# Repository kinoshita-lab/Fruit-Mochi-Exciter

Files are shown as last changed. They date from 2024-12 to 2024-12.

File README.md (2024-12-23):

# Fruit Mochi Exciter

[日本語](README.ja.md)

Mochi(Fruit Mochi) is a famous Japanese sweets, which (from my perspective) looks like trigger pads what DJs/Musicians doing some kind of cool activities!
This product enables mochi lighting to derive full potential of the mochi itself...!


<br />
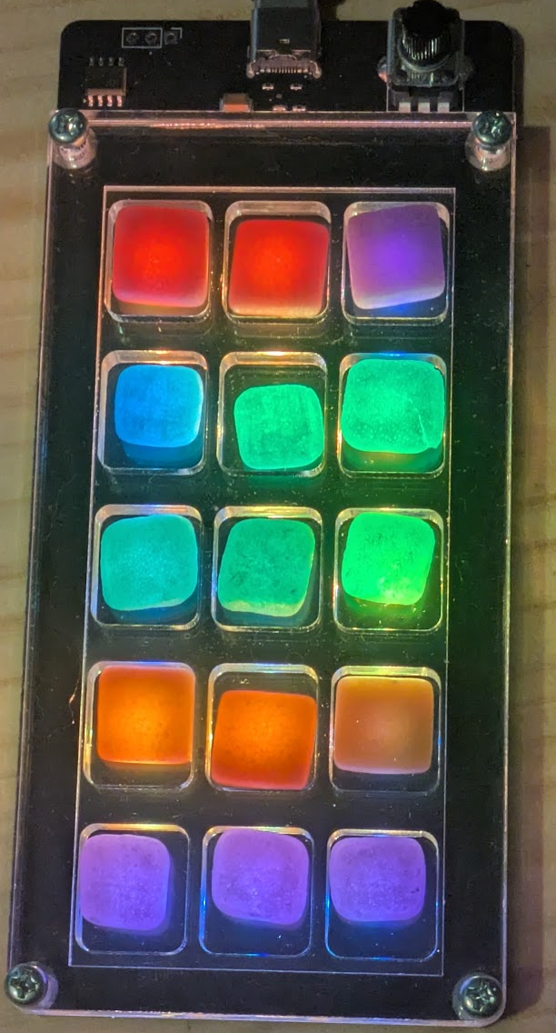
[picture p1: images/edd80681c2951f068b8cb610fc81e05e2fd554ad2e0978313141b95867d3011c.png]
  
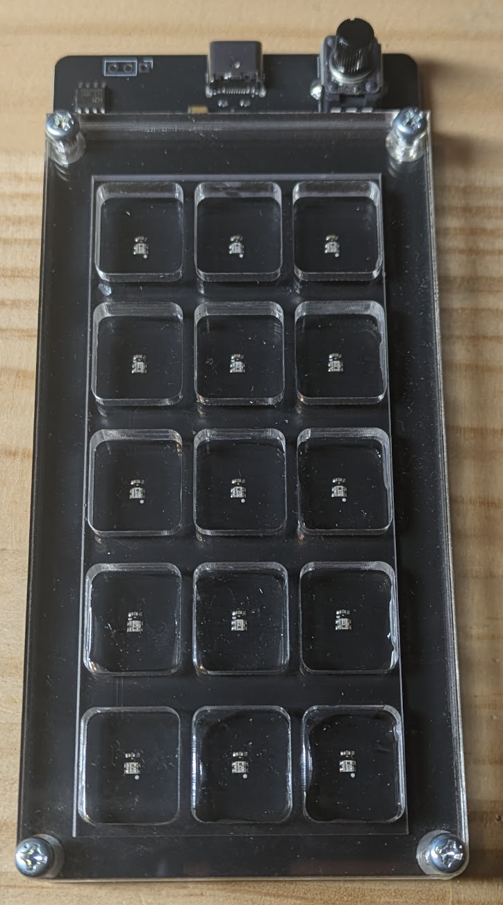
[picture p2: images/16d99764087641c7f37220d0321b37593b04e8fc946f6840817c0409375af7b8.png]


## Features

- Can change tempo via potentiometer

## Kit Contents

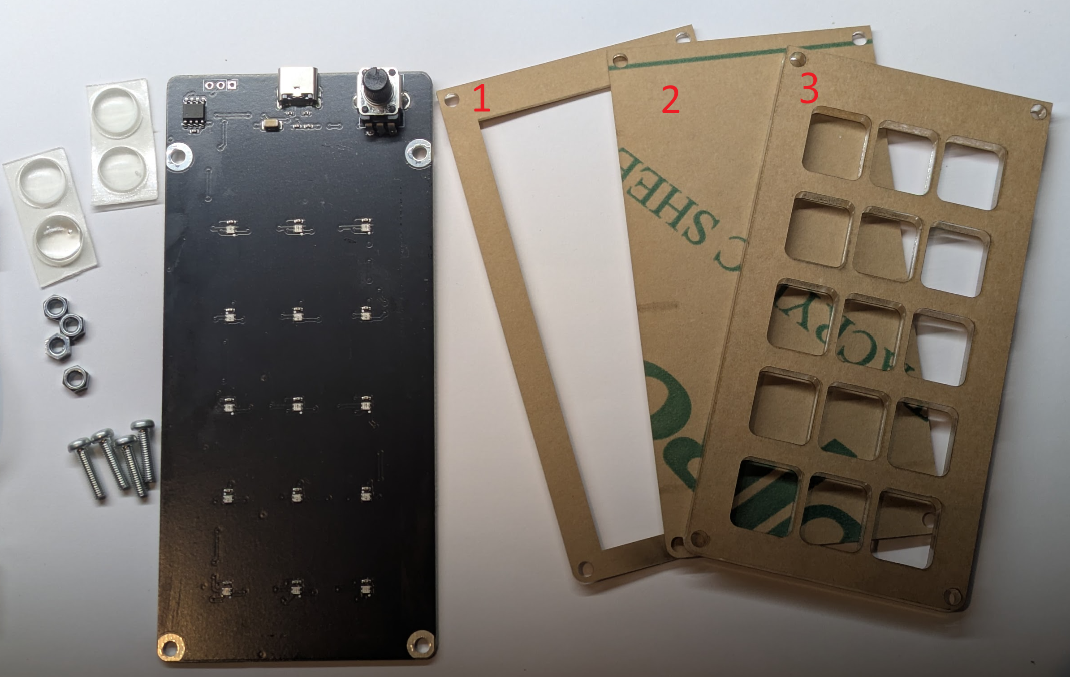
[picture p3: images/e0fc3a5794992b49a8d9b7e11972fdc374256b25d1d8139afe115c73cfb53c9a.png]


- Pre-assembled circuit board
- M3 12mm screws: 4pcs.
- M3 nuts: 4pcs.
- Acrylic boards(1, 2, 3)
- Rubber feets: 4pcs.

## What you will need

- USB Type-C cable, with connected to the power source(AC adapter, PC, etc.)
- Screwdriver
- Fruit Mochi: 15 pcs.

## How to assemble

- Remove the sealing paper on the accrylic boards.
- Put board 1 on the circuit board.
- Put board 2 on the board 1
- Put board 3 on the board 2
- Fix all with 12mm screws and nuts.

## How to use

- Place mochis on the board.
- Start lighting by connecting the USB.
- Enjoy!

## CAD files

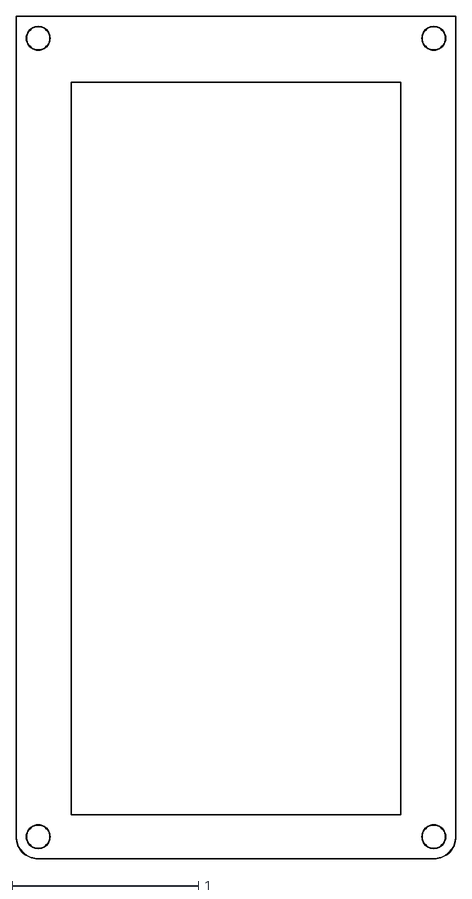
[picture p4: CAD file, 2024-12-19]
hard/Accryl/Fruit-Mochi-exciter_Acryl_Layer0-Edge_Cuts.dxf
2.36 x 4.53

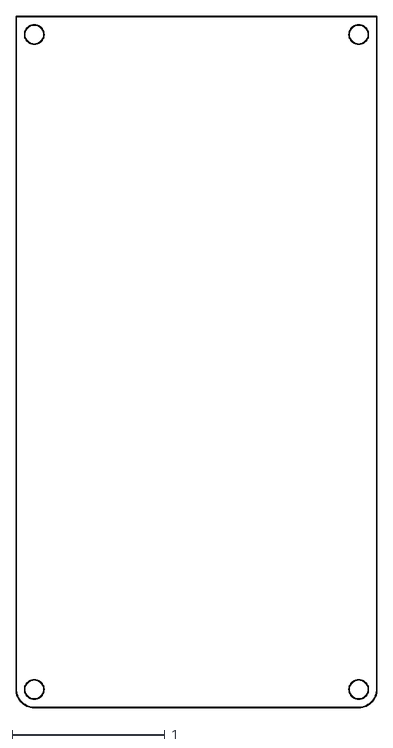
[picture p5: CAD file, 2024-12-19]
hard/Accryl/Fruit-Mochi-exciter_Acryl_Layer1-Edge_Cuts.dxf
2.36 x 4.53

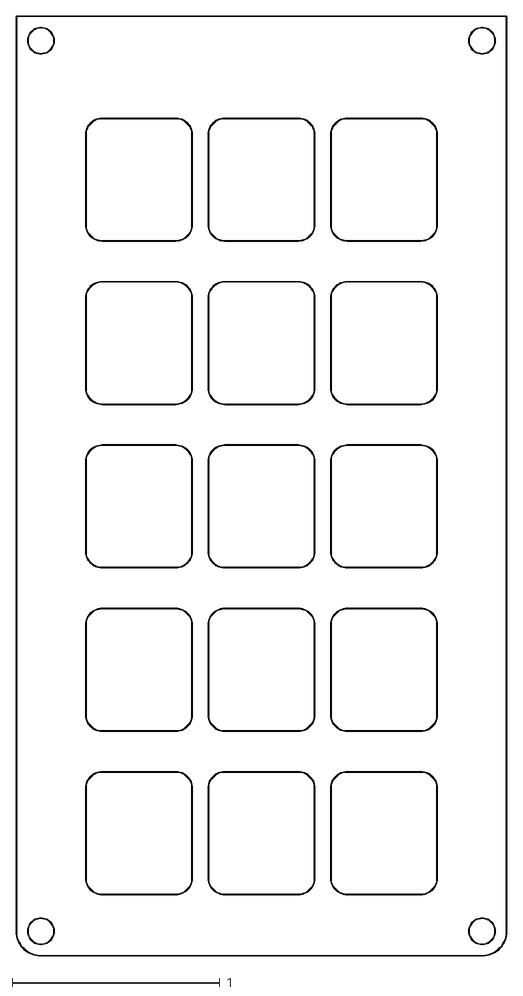
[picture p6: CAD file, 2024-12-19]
hard/Accryl/Fruit-Mochi-exciter_Acryl_Layer2-Edge_Cuts.dxf
2.36 x 4.53

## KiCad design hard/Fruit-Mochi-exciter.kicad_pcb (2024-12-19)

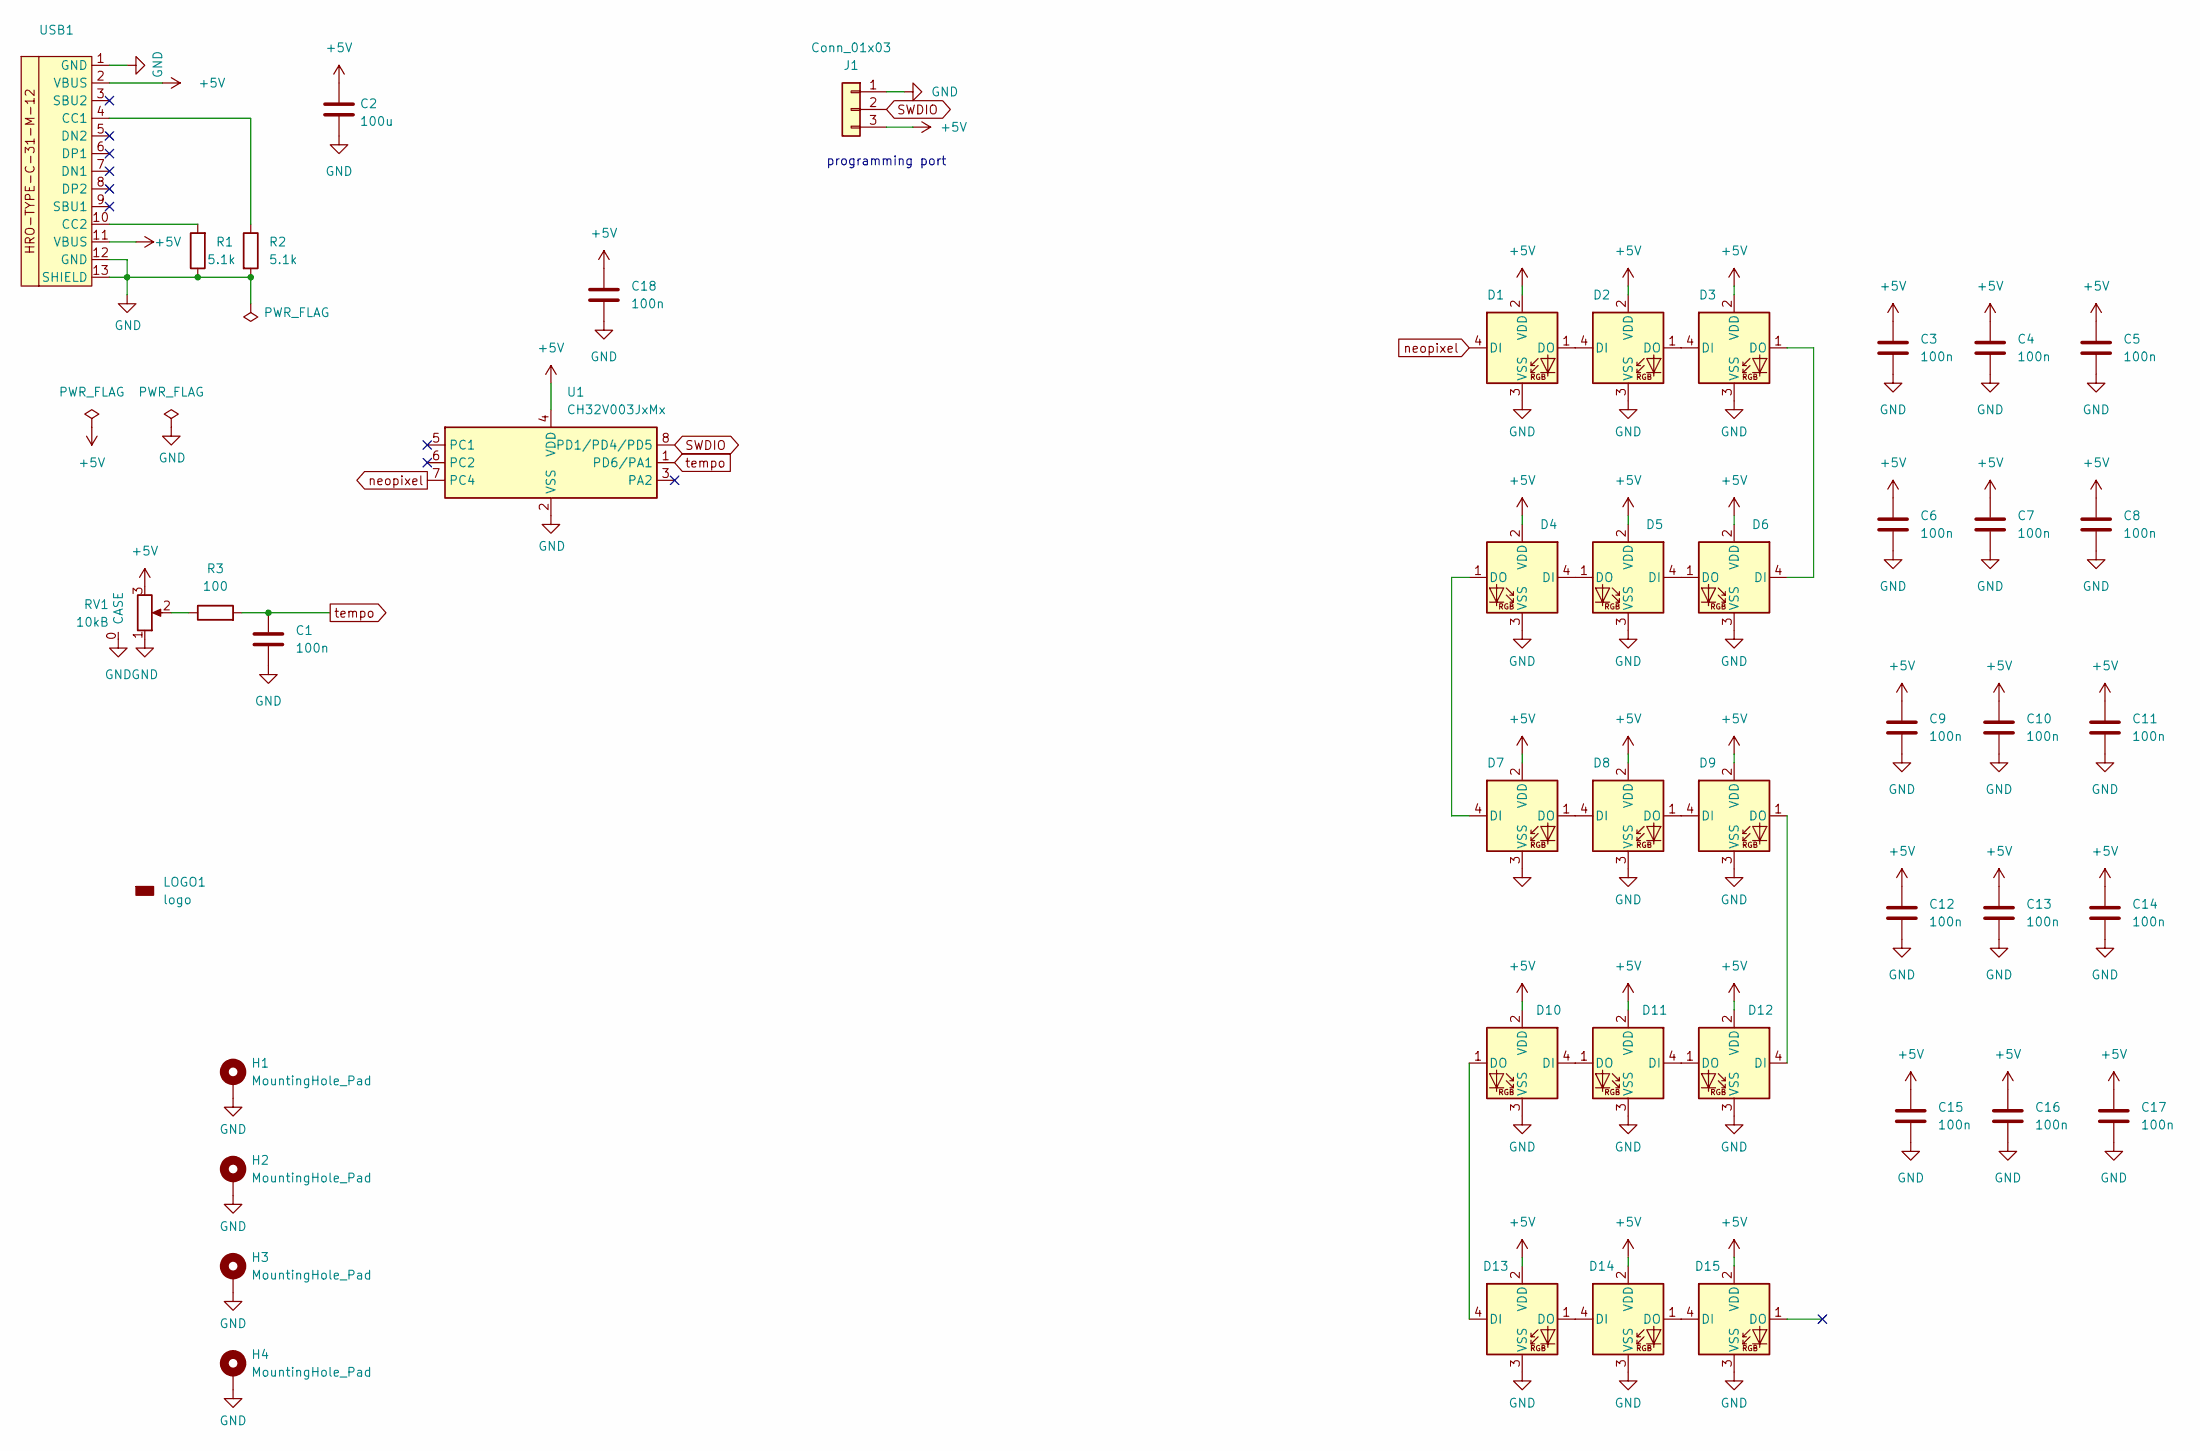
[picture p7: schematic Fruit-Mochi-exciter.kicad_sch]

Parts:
C1, C3, C4, C5, C6, C7, C8, C9, C10, C11, C12, C13, C14, C15, C16, C17, C18: 100n; C_0402_1005Metric_Pad0.74x0.62mm_HandSolder; LCSC C1525
C2: 100u; C_1206_3216Metric_Pad1.33x1.80mm_HandSolder; LCSC C312983
D1, D2, D3, D4, D5, D6, D7, D8, D9, D10, D11, D12, D13, D14, D15: LED_NeoPixel_XL-1615RGBC-WS2812B; LCSC C5349954
H1, H2, H3, H4: MountingHole_Pad; MountingHole_3.2mm_M3_Pad
J1: Conn_01x03; PinHeader_1x03_P2.54mm_Vertical
LOGO1: logo; kinoshita-logo_simplified_300dpi
R1, R2: 5.1k; R_0402_1005Metric; LCSC C25905
R3: 100; R_0402_1005Metric_Pad0.72x0.64mm_HandSolder; LCSC C106232
RV1: 10kB; Potentiometer_Alps_RK09K_Horizontal_CORRECTED; LCSC C470294
U1: CH32V003JxMx; SOP-8_3.9x4.9mm_P1.27mm; LCSC C5346354
USB1: HRO TYPE-C-31-M-08A; LCSC C2848616

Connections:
+5V: C2.1, C3.1, C4.1, C5.1, C6.1, C7.1, C8.1, C9.1, C10.1, C11.1, C12.1, C13.1, C14.1, C15.1, C16.1, C17.1, C18.1, D1.2 (VDD), D2.2 (VDD), D3.2 (VDD), D4.2 (VDD), D5.2 (VDD), D6.2 (VDD), D7.2 (VDD), D8.2 (VDD), D9.2 (VDD), D10.2 (VDD), D11.2 (VDD), D12.2 (VDD), D13.2 (VDD), D14.2 (VDD), D15.2 (VDD), J1.3, RV1.3, U1.4 (VDD), USB1.2 (VBUS), USB1.11 (VBUS)
GND: C1.2, C2.2, C3.2, C4.2, C5.2, C6.2, C7.2, C8.2, C9.2, C10.2, C11.2, C12.2, C13.2, C14.2, C15.2, C16.2, C17.2, C18.2, D1.3 (VSS), D2.3 (VSS), D3.3 (VSS), D4.3 (VSS), D5.3 (VSS), D6.3 (VSS), D7.3 (VSS), D8.3 (VSS), D9.3 (VSS), D10.3 (VSS), D11.3 (VSS), D12.3 (VSS), D13.3 (VSS), D14.3 (VSS), D15.3 (VSS), H1.1, H2.1, H3.1, H4.1, J1.1, R1.1, R2.2, RV1.0 (CASE), RV1.1, U1.2 (VSS), USB1.1 (GND), USB1.12 (GND), USB1.13 (SHIELD)
unnamed: D1.1 (DO), D2.4 (DI)
unnamed: D2.1 (DO), D3.4 (DI)
unnamed: D3.1 (DO), D6.4 (DI)
unnamed: D4.4 (DI), D5.1 (DO)
unnamed: D4.1 (DO), D7.4 (DI)
unnamed: D5.4 (DI), D6.1 (DO)
unnamed: D7.1 (DO), D8.4 (DI)
unnamed: D8.1 (DO), D9.4 (DI)
unnamed: D10.4 (DI), D11.1 (DO)
unnamed: D10.1 (DO), D13.4 (DI)
unnamed: D11.4 (DI), D12.1 (DO)
unnamed: D9.1 (DO), D12.4 (DI)
unnamed: D13.1 (DO), D14.4 (DI)
unnamed: D14.1 (DO), D15.4 (DI)
unnamed: R3.1, RV1.2
unnamed: R2.1, USB1.4 (CC1)
unnamed: R1.2, USB1.10 (CC2)
SWDIO: J1.2, U1.8 (PD1/PD4/PD5)
neopixel: D1.4 (DI), U1.7 (PC4)
tempo: C1.1, R3.2, U1.1 (PD6/PA1)

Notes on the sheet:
programming port

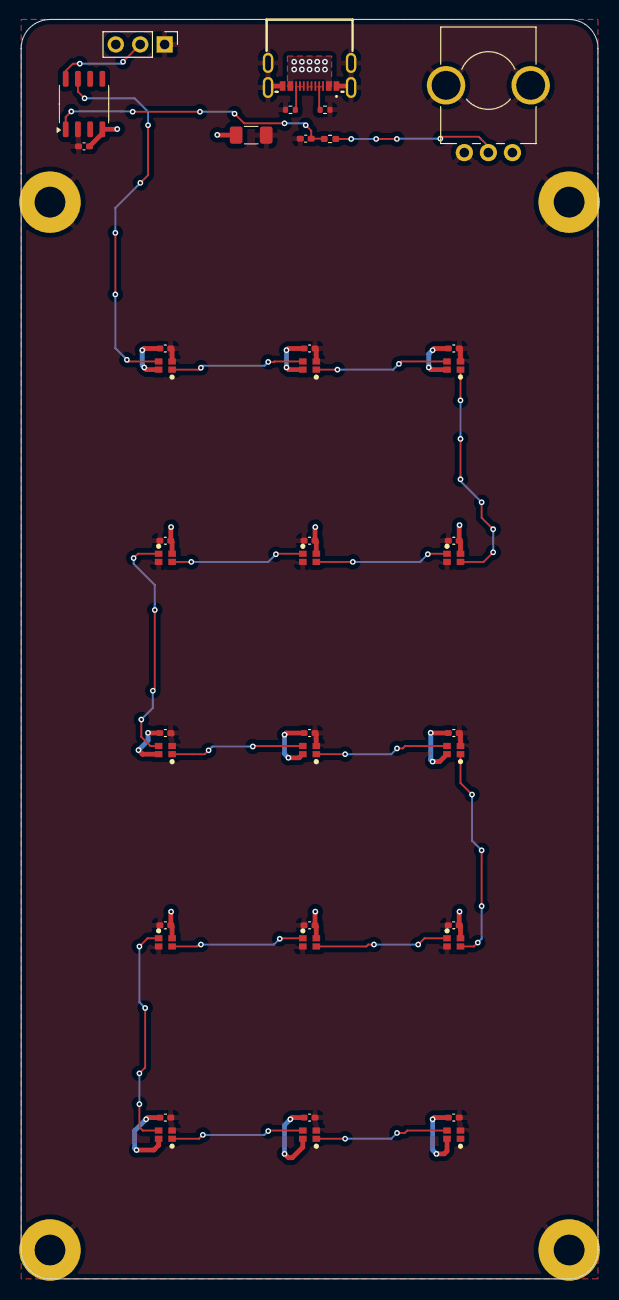
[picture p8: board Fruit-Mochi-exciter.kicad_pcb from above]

Board: 2 copper layers, 60.0 x 131.0 mm, 45 parts (1 on the bottom side), 22 nets.

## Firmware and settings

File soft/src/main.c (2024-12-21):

/**
 * @file main.c
 *
 * @author Kazuki Saita <saita@kinoshita-lab.com>
 *
 * Copyright (c) 2024 Kinoshita Lab. All rights reserved.
 *
 */
#include <stdio.h>
#include <stdlib.h>
#include <string.h>

#include "ch32v003_GPIO_branchless.h"
#include "ch32v003fun.h"

#define WS2812BSIMPLE_IMPLEMENTATION
#include "ws2812b_simple.h"

#include "debug.h"

// #define DEBUG_PRINT
#ifndef DEBUG_PRINT
#define printf(...)
#endif

#define MAX(a, b) ((a) > (b) ? (a) : (b))

#define LED_NUM 15
#define LED_PIN GPIOv_from_PORT_PIN(GPIO_port_C, 4)

uint8_t r = 0;
uint8_t g = 0;
uint8_t b = 0;
uint8_t colorData[3 * LED_NUM];

typedef struct
{
    uint8_t r;
    uint8_t g;
    uint8_t b;
} RGBStruct;

uint32_t counter = 0;

void init_rcc(void)
{
    RCC->APB2PCENR |=
        RCC_APB2Periph_GPIOA | RCC_APB2Periph_GPIOC | RCC_APB2Periph_GPIOD;
}

void init_gpio()
{
    GPIO_port_enable(GPIO_port_C);
    GPIO_port_enable(GPIO_port_D);
    GPIO_pinMode(LED_PIN, GPIO_pinMode_O_pushPull, GPIO_Speed_50MHz);
    GPIO_digitalWrite_0(LED_PIN);
    Delay_Ms(100);
}

// init ADC Ch1 6 = PD6
void adc_init(void)
{
    // ADCCLK = 24 MHz => RCC_ADCPRE = 0: divide by 2
    RCC->CFGR0 &= ~(0x1F << 11);

    // Enable GPIOD and ADC
    RCC->APB2PCENR |= RCC_APB2Periph_GPIOD | RCC_APB2Periph_ADC1;

    // PD6 is analog input chl 6
    GPIOD->CFGLR &= ~(0xf << (6 * 4)); // CNF6 = 00: Analog, MODE6 = 00: Input

    // Reset the ADC to init all regs
    RCC->APB2PRSTR |= RCC_APB2Periph_ADC1;
    RCC->APB2PRSTR &= ~RCC_APB2Periph_ADC1;

    // Set up single conversion on chl
    ADC1->RSQR1 = 0;
    ADC1->RSQR2 = 0;
    ADC1->RSQR3 = 6; // 0-9 for 8 ext inputs and two internals

    // set sampling time for chl 7
    ADC1->SAMPTR2 &= ~(ADC_SMP0 << (3 * 6));
    ADC1->SAMPTR2 |= 7 << (3 * 6); // 0:7 => 3/9/15/30/43/57/73/241 cycles

    // turn on ADC and set rule group to sw trig
    ADC1->CTLR2 |= ADC_ADON | ADC_EXTSEL;

    // Reset calibration
    ADC1->CTLR2 |= ADC_RSTCAL;
    while (ADC1->CTLR2 & ADC_RSTCAL)
        ;

    // Calibrate
    ADC1->CTLR2 |= ADC_CAL;
    while (ADC1->CTLR2 & ADC_CAL)
        ;

    // should be ready for SW conversion now
}

uint16_t adc_get(void)
{
    // start sw conversion (auto clears)
    ADC1->CTLR2 |= ADC_SWSTART;

    // wait for conversion complete
    while (!(ADC1->STATR & ADC_EOC))
        ;

    // get result
    return ADC1->RDATAR;
}

void setBufferRGB(uint8_t r, uint8_t g, uint8_t b, uint8_t* buffer,
                  uint32_t offset)
{
    offset *= 3;

    buffer[offset]     = g;
    buffer[offset + 1] = r;
    buffer[offset + 2] = b;
}

RGBStruct hsv2rgb(float H, float S, float V)
{
    float r, g, b;

    float h = H / 360;
    float s = S / 100;
    float v = V / 100;

    int i   = (int)(h * 6);
    float f = h * 6 - i;
    float p = v * (1 - s);
    float q = v * (1 - f * s);
    float t = v * (1 - (1 - f) * s);

    switch (i % 6) {
    case 0:
        r = v, g = t, b = p;
        break;
    case 1:
        r = q, g = v, b = p;
        break;
    case 2:
        r = p, g = v, b = t;
        break;
    case 3:
        r = p, g = q, b = v;
        break;
    case 4:
        r = t, g = p, b = v;
        break;
    case 5:
        r = v, g = p, b = q;
        break;
    }

    RGBStruct color;
    color.r = r * 255;
    color.g = g * 255;
    color.b = b * 255;

    return color;
}

uint32_t xorshift()
{
    static uint32_t v = 2463534242;
    v ^= v << 13;
    v ^= v >> 17;
    v ^= v << 5;
    return v;
}

int main()
{

    SystemInit();
    init_rcc();
    init_gpio();
    adc_init();
    SDI_Printf_Enable();

    while (1) {
        for (uint8_t i = 0; i < LED_NUM; i++) {
            counter += 1;
            uint8_t val = xorshift() & 0x01;

            RGBStruct rgb = hsv2rgb(counter, 100, 100);
            if (val) {
                setBufferRGB(rgb.r, rgb.g, rgb.b, colorData, i);
            } else {
                setBufferRGB(16, 16, 16, colorData, i);
            }
        }

        WS2812BSimpleSend(GPIOC, 4, colorData, 3 * LED_NUM);

        const uint16_t bpm   = MAX(30, adc_get() >> 2);
        const uint16_t delay = 60000 / bpm / 4;
        Delay_Ms(delay);
    }
}

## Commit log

2024-12-19 add pcb design
    [Fruit-Mochi-exciter.kicad_pcb, Fruit-Mochi-exciter.kicad_sch, Fruit-Mochi-exciter_Acryl_Layer0-Edge_Cuts.dxf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]
2024-12-21 move pcb design into hard folder
    [Fruit-Mochi-exciter.kicad_pcb, Fruit-Mochi-exciter.kicad_sch, Fruit-Mochi-exciter_Acryl_Layer0-Edge_Cuts.dxf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]
2024-12-23 README.md の更新
